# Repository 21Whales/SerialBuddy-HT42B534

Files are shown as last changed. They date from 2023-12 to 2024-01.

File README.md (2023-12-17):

# SerialBuddy-HT42B534

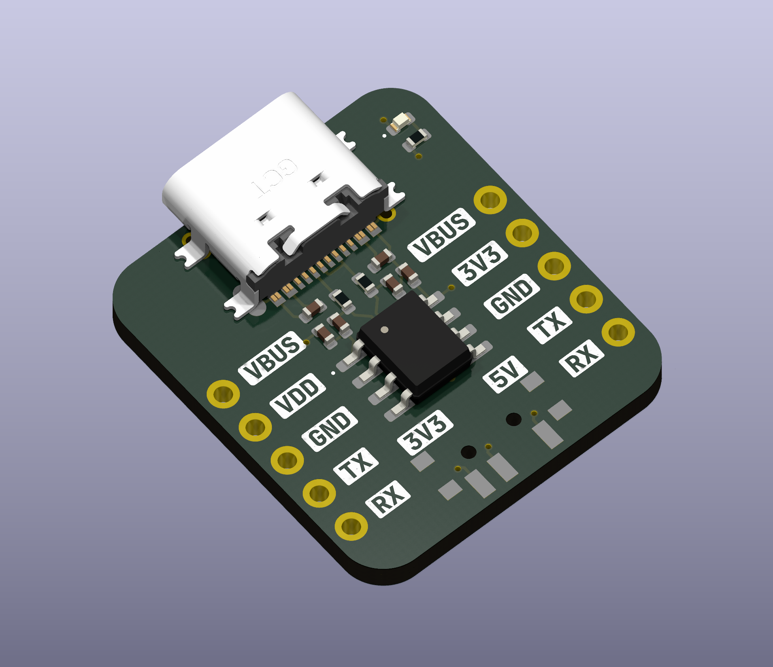
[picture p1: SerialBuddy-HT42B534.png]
SerialBuddy-HT42B534 Logo


[Schematics/Board](https://kicanvas.org/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)

## Overview

SerialBuddy-HT42B534 is a USB to UART interface based on the Holtek HT42B534 chip, designed with a focus on simplicity and versatility. It is suitable for breadboard use, featuring clearly labeled pins and supporting dual voltage supply (3.3V and 5V). The device also offers selectable I/O voltage (3.3V or 5V), and excludes less commonly used pins like RTS and CTS for a streamlined user experience. SerialBuddy-HT42B534 is an open-source hardware project distributed under the BSD 3-Clause License.

## Features

- USB to UART interface
- Breadboard-friendly design
- Clearly labeled pins for easy reference
- Dual voltage supply (3.3V and 5V)
- Selectable I/O voltage (3.3V or 5V)
- Excludes less commonly used pins like RTS and CTS for simplicity
- Open-source hardware under BSD 3-Clause License

## Pin Names

- **TX**: Transmit Data
- **RX**: Receive Data
- **GND**: Ground
- **VDD**: Power Supply (Selectable: 3.3V or 5V)
- **VBUS**: 5V from USB Bus
- **3V3**: 3.3V from internal regulator

## License

SerialBuddy-HT42B534 is distributed under the [BSD 3-Clause License](LICENSE).

## Contributing

We welcome contributions! Feel free to submit bug reports, feature requests, or pull requests.

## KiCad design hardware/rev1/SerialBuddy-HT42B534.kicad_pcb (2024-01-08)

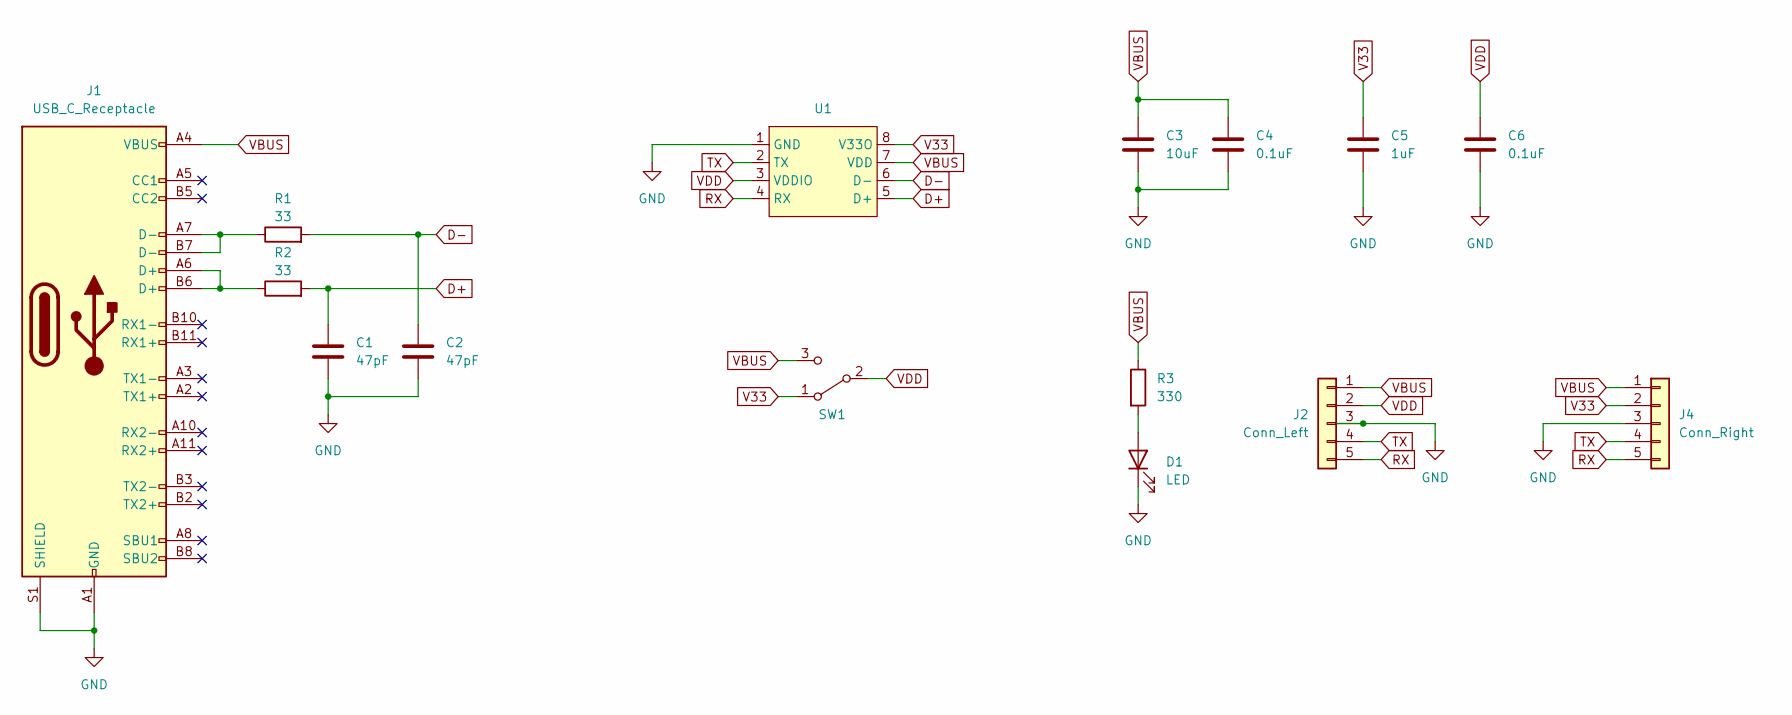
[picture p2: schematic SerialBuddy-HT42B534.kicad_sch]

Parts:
C1, C2: 47pF; C_0402_1005Metric; LCSC C1567
C3: 10uF; C_0402_1005Metric; LCSC C15525
C4, C6: 0.1uF; C_0402_1005Metric; LCSC C1525
C5: 1uF; C_0402_1005Metric; LCSC C52923
D1: LED; LED_0402_1005Metric; LCSC C434449
J1: USB_C_Receptacle; USB_C_Receptacle_G-Switch_GT-USB-7010ASV; LCSC C2988369
J2: Conn_Left; Conn_1x05
J4: Conn_Right; Conn_1x05
R1, R2: 33; R_0402_1005Metric; LCSC C25105
R3: 330; R_0402_1005Metric; LCSC C25104
SW1: SW_SPDT; MSS12C02; LCSC C3008585
U1: SO-8_3.9x4.9mm_P1.27mm; LCSC C493294

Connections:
D+: C1.1, R2.2, U1.5 (D+)
D-: C2.1, R1.2, U1.6 (D-)
GND: C1.2, C2.2, C3.2, C4.2, C5.2, C6.2, D1.1 (K), J1.A1 (GND), J1.A12 (GND), J1.B1 (GND), J1.B12 (GND), J1.S1 (SHIELD), J2.3, J4.3, U1.1 (GND)
unnamed: D1.2 (A), R3.2
unnamed: J1.A6 (D+), J1.B6 (D+), R2.1
unnamed: J1.A7 (D-), J1.B7 (D-), R1.1
RX: J2.5, J4.5, U1.4 (RX)
TX: J2.4, J4.4, U1.2 (TX)
V33: C5.1, J4.2, SW1.1 (A), U1.8 (V33O)
VBUS: C3.1, C4.1, J1.A4 (VBUS), J1.A9 (VBUS), J1.B4 (VBUS), J1.B9 (VBUS), J2.1, J4.1, R3.1, SW1.3 (C), U1.7 (VDD)
VDD: C6.1, J2.2, SW1.2 (B), U1.3 (VDDIO)

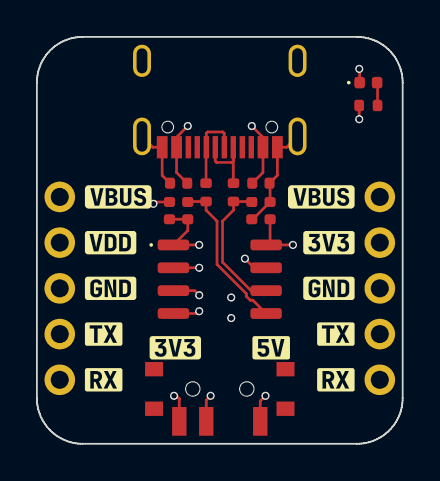
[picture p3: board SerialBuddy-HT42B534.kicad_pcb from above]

Board: 4 copper layers, 20.3 x 22.6 mm, 15 parts (0 on the bottom side), 11 nets.

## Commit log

2023-12-17 add readme
    [SerialBuddy-HT42B534.kicad_pcb]
2023-12-17 update solder mask to say 3V3 instead of 3.3V or V33
    [SerialBuddy-HT42B534.kicad_pcb]
2023-12-17 add link to board/schematics
2024-01-08 fix label
    [SerialBuddy-HT42B534.kicad_pcb]
